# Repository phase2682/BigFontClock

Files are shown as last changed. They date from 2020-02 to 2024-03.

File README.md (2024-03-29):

# BigFontClock
Code for Large Format Number Clock UTC and Local time

Clock display uses all four lines of LCD to display large numbers

Code is written in Python 3.6 for use with Raspbery pi.  Library files are basic code for  
LCD operation and generation of date and time in BCD format

.svg file for enclosure 

checkout https://www.ai6xg.com/post/big-font-clock-relieve-for-old-eyes for more details on software, hardware and build

A PC board for interfacing the LCD to the Rpi W was built in Kicad, schematic and board files now included.  The board has
a 555 based PWM dimmer for a backlit LCD display.  Enclosure has been modified with additional cutout for brightness control.  

See the updated details as https://www.ai6xg.com/post/big-font-clock-update-backlit-lcd     Set up details have also been added.

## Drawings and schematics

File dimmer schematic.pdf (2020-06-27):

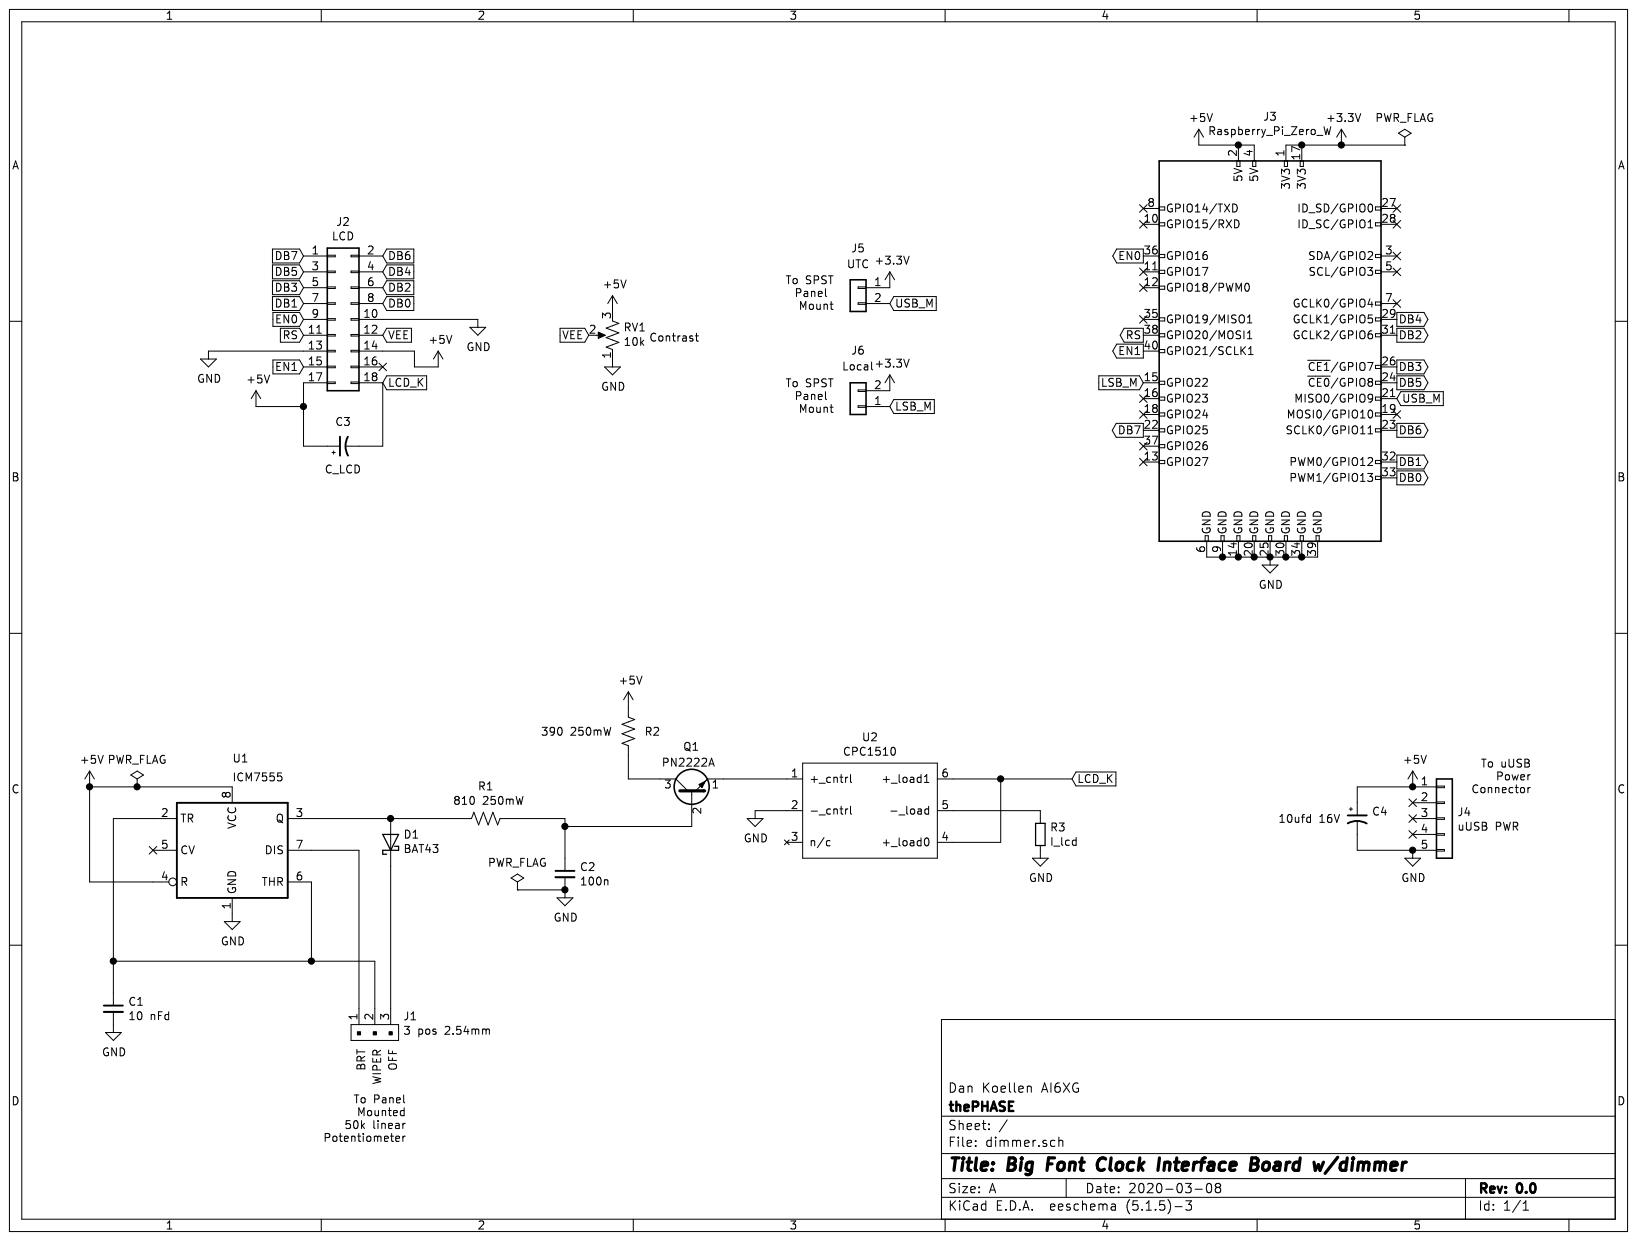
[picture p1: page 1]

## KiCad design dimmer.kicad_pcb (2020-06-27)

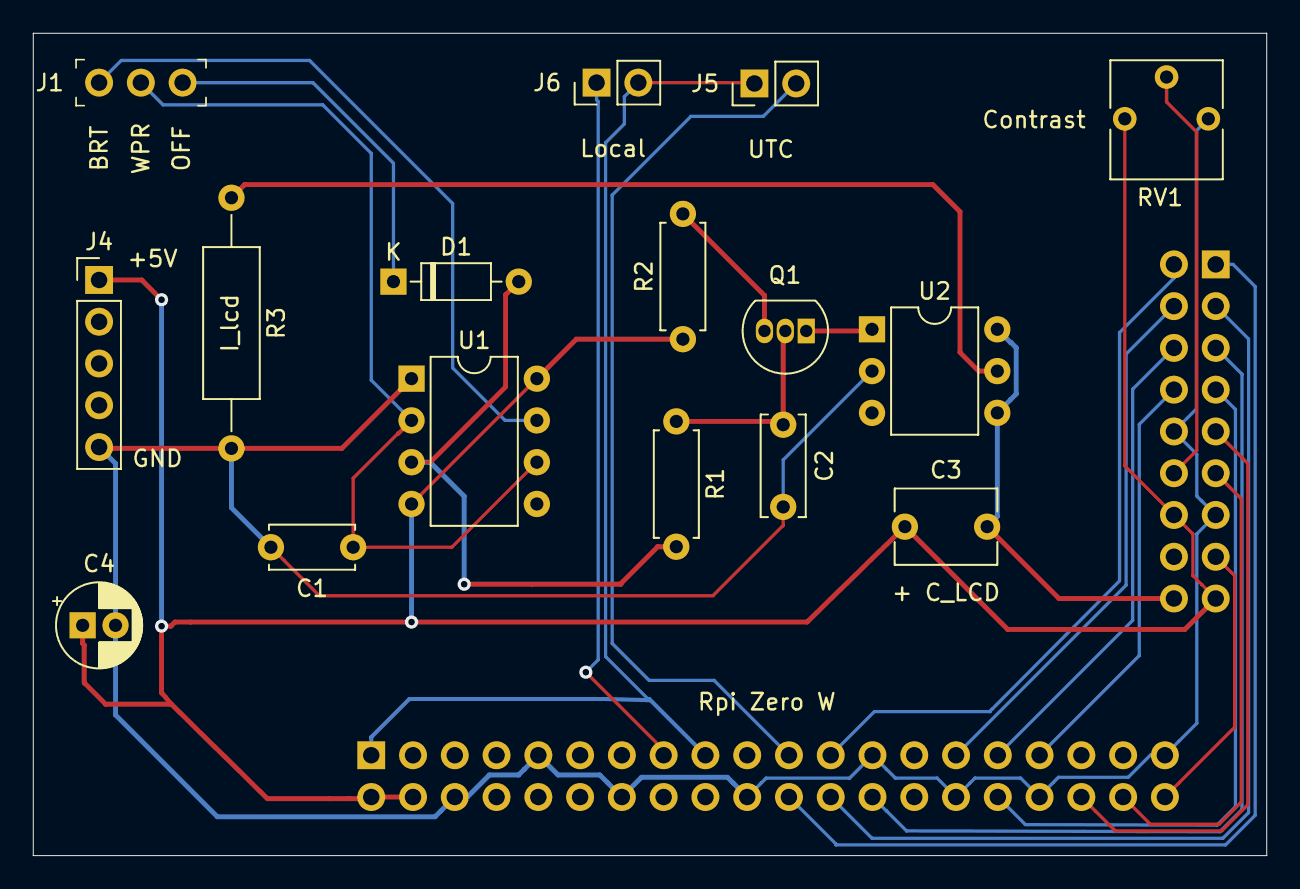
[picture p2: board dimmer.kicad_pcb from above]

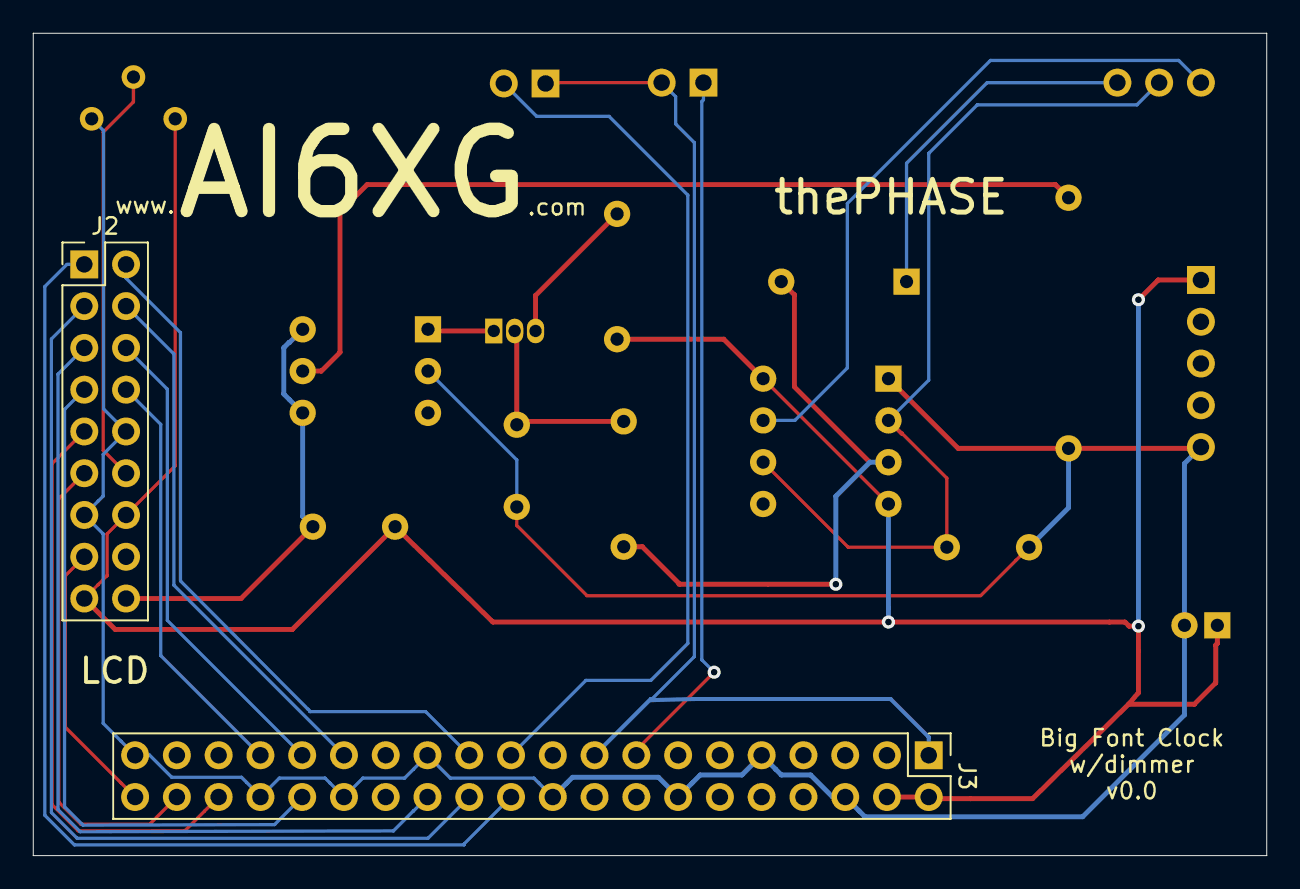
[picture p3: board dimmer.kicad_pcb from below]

Board: 2 copper layers, 75.0 x 50.0 mm, 18 parts (2 on the bottom side), 26 nets.

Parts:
C1: 10 nFd; C_Disc_D5.0mm_W2.5mm_P5.00mm
C2: 100n; C_Disc_D6.0mm_W2.5mm_P5.00mm
C3: + C_LCD; C_Disc_D6.0mm_W4.4mm_P5.00mm
C4: 10ufd 16V; CP_Radial_D5.0mm_P2.00mm
D1: BAT43; D_DO-35_SOD27_P7.62mm_Horizontal
J1: 3 pos 2.54mm; PinHeader_1x3_P2.54_Drill1.1mm
J2: LCD; PinHeader_2x09_P2.54mm_Vertical
J3: Raspberry_Pi_Zero_W; PinHeader_2x20_P2.54mm_Vertical
J4: uUSB PWR; PinHeader_1x05_P2.54mm_Vertical
J5: UTC; PinHeader_1x02_P2.54mm_Vertical
J6: Local; PinHeader_1x02_P2.54mm_Vertical
Q1: PN2222A; TO-92_Inline
R1: 810 250mW; R_Axial_DIN0207_L6.3mm_D2.5mm_P7.62mm_Horizontal
R2: 390 250mW; R_Axial_DIN0207_L6.3mm_D2.5mm_P7.62mm_Horizontal
R3: I_lcd; R_Axial_DIN0309_L9.0mm_D3.2mm_P15.24mm_Horizontal
RV1: 10k; Potentiometer_Vishay_T73YP_Vertical
U1: ICM7555; DIP-8_W7.62mm
U2: CPC1510; DIP-6_W7.62mm

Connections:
+3V3: J3.1, J3.17, J5.1, J6.2
+5V: C3.1, C4.1, J2.14, J2.17, J3.2, J3.4, J4.1, R2.1, RV1.3, U1.4, U1.8
DB0: J2.8, J3.33
DB1: J2.7, J3.32
DB2: J2.6, J3.31
DB3: J2.5, J3.26
DB4: J2.4, J3.29
DB5: J2.3, J3.24
DB6: J2.2, J3.23
DB7: J2.1, J3.22
EN0: J2.9, J3.36
EN1: J2.15, J3.40
GND: C1.2, C2.2, C4.2, J2.10, J2.13, J3.6, J3.9, J3.14, J3.20, J3.25, J3.30, J3.34, J3.39, J4.5, R3.2, RV1.1, U1.1, U2.2
LCD_K: C3.2, J2.18, U2.4, U2.6
LSB_M: J3.15, J6.1
unnamed: C1.1, J1.2, U1.2, U1.6
unnamed: C2.1, Q1.2, R1.1
unnamed: D1.1, J1.3
unnamed: D1.2, R1.2, U1.3
unnamed: J1.1, U1.7
unnamed: Q1.1, U2.1
unnamed: Q1.3, R2.2
unnamed: R3.1, U2.5
RS: J2.11, J3.38
USB_M: J3.21, J5.2
VEE: J2.12, RV1.2

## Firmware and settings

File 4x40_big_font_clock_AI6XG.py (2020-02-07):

#Dan Koellen AI6XG Jan 2020
#
#4x40_big_font_clock_AI6XG.py
#change GPIO assignments for board layout

import datetime
import time
from LCD_2E_AI6XG import *
from LCD_BIG_FONT_AI6XG import *
from return_time_date_AI6XG import *
#import RPi.GPIO as gpio						#uncomment if gpio not setup previously

mode_pin_lsb = 22								#mode pin lsb 2^0
mode_pin_usb = 9								#mode pin usb 2^1
mode_flag = 0									#mode changed = 1,no mode change = 0

toggle_dur = 7									#display duration in seconds in toggle mode
toggle_dur *= 1.0								#force to float


#Function Definitions for Clock display 
#place colon : at left
def colon(left):
	lcd_goto(left, 0)							#LCD0 line 0 position 'left'
	lcd_putch(0x20, 0)
	
	lcd_goto(left + 0x40, 0)					#LCD0 line 1 position 'left'
	lcd_putch(0x05, 0)	
	
	lcd_goto(left, 1)							#LCD1 line 0 position 'left'
	lcd_putch(0x01, 1)
	
	lcd_goto(left + 0x40, 1)					#LCD1 line 1 position 'left'
	lcd_putch(0x20, 1)
	
#place a blank space at left
def blank(left):
	lcd_goto(left, 0)
	lcd_putch(0x20, 0)
	
	lcd_goto(left + 0x40, 0)
	lcd_putch(0x20, 0)	
	
	lcd_goto(left, 1)
	lcd_putch(0x20, 1)
	
	lcd_goto(left + 0x40, 1)
	lcd_putch(0x20, 1)
	
#place a single space dash at left
def dash(left):
	lcd_goto(left, 0)
	lcd_putch(0x20, 0)
	
	lcd_goto(left + 0x40, 0)
	lcd_putch(0x01, 0)	
	
	lcd_goto(left, 1)
	lcd_putch(0x20, 1)
	
	lcd_goto(left + 0x40, 1)
	lcd_putch(0x20, 1)
	
#place a period at left
def period(left):
	lcd_goto(left, 0)
	lcd_putch(0x20, 0)
	
	lcd_goto(left + 0x40, 0)
	lcd_putch(0x20, 0)	
	
	lcd_goto(left, 1)
	lcd_putch(0x20, 1)
	
	lcd_goto(left + 0x40, 1)
	lcd_putch(0x05, 1)

#display colon at position pos
#col_on/100 sec colon on, 1 - col_on/100 second colon off
#needs continuous time access for blink
#col_on blink < 100 --->steady = 100 blank = 0
#colon_display(pos, col_on) 
def colon_display(pos, col_on):
	if col_on > 100:
		col_on = 100
	now = datetime.datetime.now()
	if now.microsecond <= col_on * 10000:
		colon(pos)
	else:
		blank(pos)
	
#time displayed at position left
#colon may be placed at left + 7
#time_bcd[hours_tens, hours_ones, minutes_tens, minutes_ones]
#time_display(time_bcd, left) 
def time_display(time_bcd, left):
	big_write(time_bcd[0],left)						#display hours_tens
	big_write(time_bcd[1],left + 4)					#display hours_ones
	big_write(time_bcd[2],left + 8)					#display minutes_tens
	big_write(time_bcd[3], left + 12)				#display minutes_ones

#date displayed at position left
#dash = 1/period = 0 placed at left + 7
#date_bcd[month_tens, month_ones, day_tens, day_ones, date_dash]
#date_display(date_bcd, left, date_dash) 
def date_display(date_bcd, left, date_dash):
	big_write(date_bcd[0],left)						#display month_tens
	big_write(date_bcd[1],left + 4)					#display month_ones
	big_write(date_bcd[2],left + 8)					#display day_tens
	big_write(date_bcd[3], left + 12)				#display day_ones
	if date_dash:									#display dash or period
		dash(left + 7)
	else:
		period(left + 7)

#check for mode
#check_mode(mode_1_pin, mode_0_pin)
def check_mode(mode_1_pin, mode_0_pin):
	global mode_toggle
	mode_0 =gpio.input(mode_0_pin)
	mode_1 =gpio.input(mode_1_pin)
	mode_now = ((mode_1 <<1) & 0b10) + mode_0		#convert to two bits
	mode_toggle = 0
	if mode_now == 0b11:							#set toggle flag for mode 3
		mode_now = 0b01
		mode_toggle = 1
	return mode_now


#set up gpios for LCD
#Setup BCM gpio for LCD, EN0 enable for LCD0, EN1 for LCD1
#lcd_setup_gpios(DB4, DB5, DB6, DB7, EN0, EN1, RS)
lcd_setup_gpios(5,8,11,25,16,21,20)

#setup gpios for this program
#gpio.setmode(gpio.BCM)								
gpio.setup(mode_pin_lsb, gpio.IN, pull_up_down = gpio.PUD_DOWN)
gpio.setup(mode_pin_usb, gpio.IN, pull_up_down = gpio.PUD_DOWN)

#initialize toggle timer
last_toggle = 0

#initialize and clear LCD 0
lcd_init(0)
lcd_clear(0)


#initialize and clear LCD 1
lcd_init(1)
lcd_clear(1)


#generate custom characters for big font
generate_big()

lcd_goto(0x00,0)
lcd_goto(0x40,1)

#clock mode selection
mode = check_mode(mode_pin_usb, mode_pin_lsb)				#mode at startup

#add mode pin interrupts
gpio.add_event_detect(mode_pin_lsb, gpio.BOTH,bouncetime = 300)
gpio.add_event_detect(mode_pin_usb, gpio.BOTH, bouncetime = 300)

#display time and date at startup
if mode == 0 or mode == 1:
	tme = return_time(UTC = 0)
	time_display(tme, 0)							#display local time starting at position 0
	
if mode ==1:
	dte = return_date(0)
	date_display(dte, 20, 0)						#display local date starting at position 20					

if mode == 0:
	tme = return_time(UTC = 1)
	time_display(tme, 20)							#display UTC time starting at position 20
	big_write('z',37)
	
if mode == 2:
	tme = return_time(UTC = 1)
	time_display(tme, 0)							#display UTC time starting at position 0
	dte = return_date(1)
	date_display(dte, 20, 0)						#display UTC date starting at position 20
	big_write(10,37)


while(1 == 1):
	if mode == 0 or mode ==1:						#local colon mode
		colon_display(7, 50)
	if mode == 0:									#UTC colon mode
		colon_display(pos = 27, col_on = 0)
	if mode == 2:									#UTC colon mode
		colon_display(7, 0)

	if gpio.event_detected(mode_pin_lsb):					#check mode at interupt
		mode = check_mode(mode_pin_usb, mode_pin_lsb)
		mode_flag = 1										#mode has changed 
		
	if gpio.event_detected(mode_pin_usb):					#check mode at interupt
		mode = check_mode(mode_pin_usb, mode_pin_lsb)
		mode_flag = 1
	
	toggle_now = time.time()								#toggle timer
	if toggle_now - last_toggle > toggle_dur and  mode_toggle:		#test for toggle duration and mode
		last_toggle = toggle_now
		mode ^= 0b11												#toggle mode
		mode_flag = 1
		
	now = datetime.datetime.now()
	if now.second == 0 or mode_flag:						#only at change of minute or mode
		if mode == 0 or mode == 1:
			tme = return_time(UTC = 0)
			time_display(tme, 0)							#display local time starting at position 0
			
		if mode == 1:
			dte = return_date(0)
			date_display(dte, 20, 0)						#display local date starting at position 20
			blank(37)										#blank last three positions
			blank(38)
			blank(39)

		if mode == 0:
			tme = return_time(UTC = 1)						
			time_display(tme, 20)							#display UTC time starting at position 20
			big_write('Z', 37)
			
		if mode == 2:
			tme = return_time(UTC = 1)
			time_display(tme, 0)							#display UTC time starting at position 0
			dte = return_date(1)
			date_display(dte, 20, 0)						#display UTC date starting at position 20
			big_write('Z', 37)
		
		mode_flag = 0										#clear mode flag
		time.sleep(.2)										#allow time for display to update
	

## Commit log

2020-06-27 add interface and dimmer PC board to project
2020-06-27 Added dimmer interface board files
    [dimmer.kicad_pcb, dimmer.sch]
2020-06-28 enclosure with cutout for back light dimmer pot
